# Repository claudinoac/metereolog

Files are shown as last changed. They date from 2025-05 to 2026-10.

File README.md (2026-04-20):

# 🌦️ Metereolog

This project involves the development of weather station and a platform capable of collecting data from various sensors, transmitting them to a central platform, storing them, and making them available through a web interface for visualization and analysis. The architecture is modular and scalable, using modern technologies for each stage of the process.

## 1. Project Overview

The main goal is to create a complete system for weather monitoring. This includes acquiring raw data from sensors, efficiently communicating this data to a central server, persistent storage in a time-series optimized database, and finally, visually and interactively presenting this data to users through a web application. Modularity allows for the easy addition of new sensors or replacement of components without affecting the whole system.

## 2. Project Architecture and Features

The architecture is distributed and based on microservices and asynchronous communication, as shown in the diagram. The main features include:

- **Distributed Data Collection:** Sensors are connected to embedded devices (HELTEC WiFi LoRa v3) that act as the network's "edge".
- **Local Gateways**: One local internet-connected dievice that aggregate data from stations in the region via LoRaWAN and transmit over the internet to the web platform via MQTT. 
- **Asynchronous, Message-Oriented Communication:** The MQTT protocol is used to transmit data from gateways to the message broker (RabbitMQ), ensuring low latency and resilience.
- **Centralized Message Processing:** RabbitMQ acts as a central hub for all sensor messages, enabling routing and processing by other components.
- **Optimized Data Persistence:** PostgreSQL and TimescaleDB provide a robust relational database optimized for time-series data.
- **RESTful API:** Facilitates communication between the frontend and backend, offering access to platform data and functionality.
- **Intuitive User Interface:** A modern, responsive web app allows for visualization and management of station data.
- **Containerization (Docker):** Simplifies deployment, portability, and environment management.
- **Modularity:** Each system component is independent, allowing isolated development and maintenance.

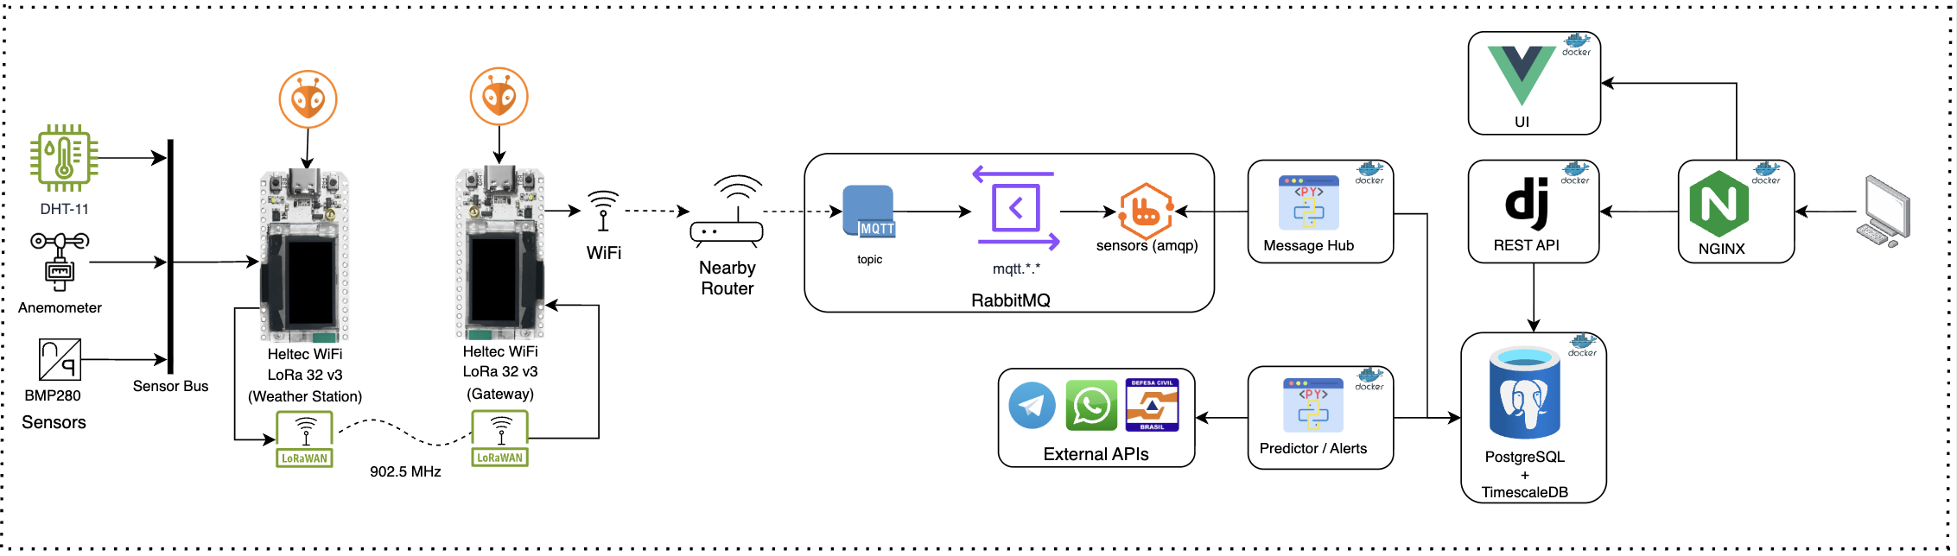
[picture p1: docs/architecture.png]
Project Architecture Diagram


## 3. Modular Project Structure and Technologies Used

### 3.1. Data Acquisition Module (Hardware and Firmware)

- **Sensors:**
  - **DHT-11:** Measures temperature and humidity.
  - **Anemometer:** Measures wind speed.
  - **Wind Direction Sensor:** Measures wind direction.
  - **MQ-6:** Measures petroleum-based gas such as propane and butane

- **Heltec WiFi LoRa 32 v3 (Sensor Bus / Weather Station):**
  - Microcontroller responsible for reading sensor data.
  - Acts as the local station’s “brain”.
  - Transmit sensor data to the Gateway node via LoRaWAN
  - **Technologies:** PlatformIO (C++ SDK), LoRaWAN, WiFi.
  - **Features:**
    - Base libraries for each sensor and peripherals (DHT-11, Anemometer, Wind Direction, WiFi, LoRa, etc.).
    - Structured firmware codebase.
    - Local wifi network to view real-time sensors data.
    - Firmware update via OTA (WiFi).
    - Doesn't depend on internet (data transmission via LoRaWAN).

- **Heltec WiFi LoRa 32 v3 (Gateway):**
  - Microcontroller responsible for receiving data from stations via LoRaWAN
  - Publishes sensor data from stations to the MQTT broker.
  - Firmware update via OTA (WiFi).
  - MQTT integration for data transmission.
  - **Technologies:**: PlatformIO (C++ SDK), LoRaWAN, WiFi.
  - **Features:**
    - Base libraries for peripherals (WiFi, LoRa, etc.)
    - Can route data from multiple stations on LoRaWAN reach.
    - Routes data to MQTT broker based on each station specs (credentials, topics).
    - Structured firmware codebase.
    - Firmware update via OTA (WiFi).

### 3.2. Communication and Messaging Module

- **RabbitMQ + MQTT Plugin:**
  - Central message broker for the system.
  - Receives MQTT messages from ESP-32.
  - Forwards them to subscribed components.
  - **Features:**
    - Reliable message delivery.
    - Decoupling producers and consumers.
    - Scalability.
  - **Topic Notation:**  
    - `<device_uid>/<sensor_uid>` = MQTT topics  
    - `mqtt.*` = wildcard listener  
    - `sensors (amqp)` = AMQP forwarding

### 3.3. Data Processing and Persistence Module

- **Message Hub:**
  - Consumes messages from RabbitMQ (`sensors (amqp)`).
  - Validates, transforms, enriches, and stores data.
  - **Technology:** Django (Python).
  - **Features:**
    - Sensor data processing logic.
    - Integration with PostgreSQL + TimescaleDB.

- **PostgreSQL + TimescaleDB:**
  - **PostgreSQL:** Stores users, devices, sensors, roles, permissions, dashboards.
  - **TimescaleDB:** Optimized for time-series sensor readings.
  - **Features:**
    - Efficient data storage (`SensorReading` table).
    - Complex historical query support.
    - System-wide entity management.

### 3.4. Backend Module (API)

- **Django REST API:**
  - Handles communication between frontend and backend.
  - Exposes data and operations through endpoints.
  - **Technology:** Django (Python).
  - **Features:**
    - CRUD endpoints for:
      - Organization (admin only)
      - Role
      - User
      - Device
      - Sensor
      - Dashboards
    - Login endpoint for user authentication.

### 3.5. Frontend Module (User Interface)

- **User Interface (UI):**
  - Web app for interacting with the system.
  - Visualizes sensor data using dashboards.
  - **Technologies:** Vue.js, Quasar, Chart.js.
  - **Features:**
    - Manage Organizations, Users, Devices, Sensors.
    - Create and view custom dashboards.
    - User login.

### 3.6. Web Server Module

- **NGINX:**
  - Reverse proxy for frontend and backend.
  - Serves frontend static files.
  - Manages routing, SSL/TLS, load balancing.
  - **Features:**
    - Optimized content delivery.
    - Unified socket for frontend/backend.
    - Simplified domain/port configuration.

## 4. General Project Features

- **Automated Data Collection:** Continuous readings of temperature, humidity, wind speed/direction, dust/smoke, air quality.
- **Reliable Data Transmission:** MQTT and RabbitMQ ensure delivery.
- **Efficient Time-Series Storage:** TimescaleDB optimized for volume and performance.
- **Entity Management:** Register and manage users, orgs, devices, sensors.
- **Real-Time & Historical Visualization:** Custom dashboards for monitoring.
- **Robust API:** Enables integration and future development.
- **Authentication & Authorization:** Role- and permission-based access.
- **Modularity & Scalability:** Easy to extend sensors, logic, or UI.
- **Simplified Deployment:** Docker streamlines setup and deployment.

## Database Schema
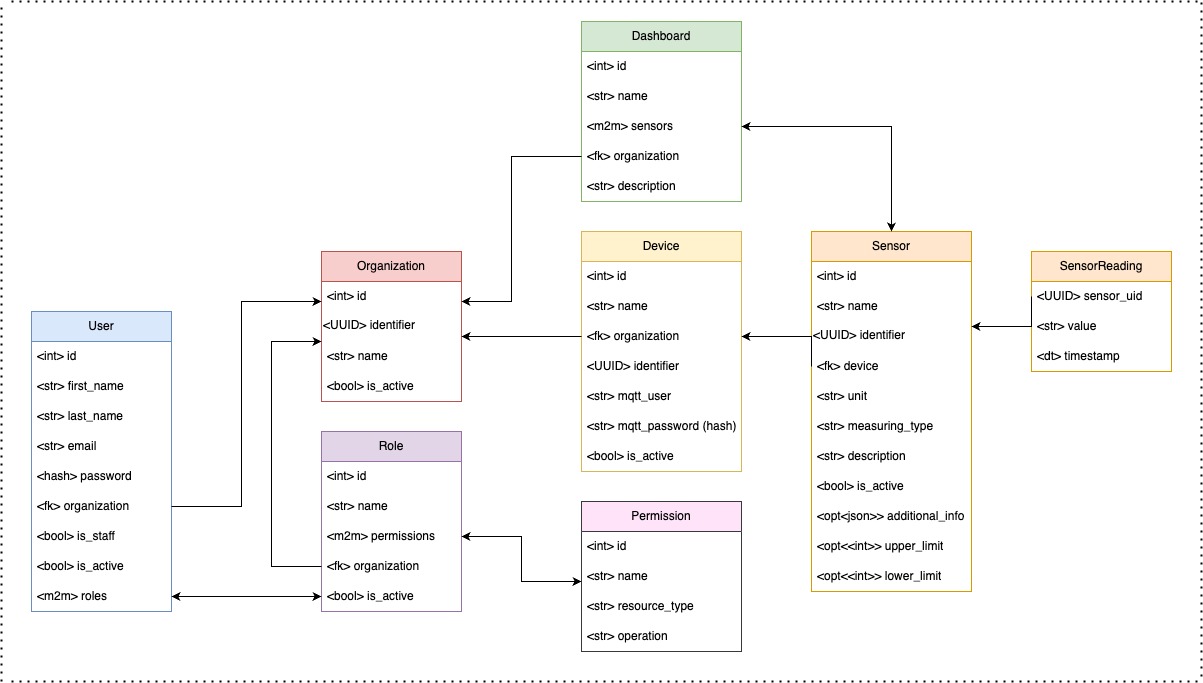
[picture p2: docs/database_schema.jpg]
Database Schema


The database schema represents the backend structure for a the web platform, where organizations can manage users, devices, sensors, and dashboards. It is designed with flexibility and scalability in mind, enabling role-based access control, sensor data collection, and customizable dashboards.

At the core of the system is the Organization entity, which acts as a tenant and groups together various resources such as users, devices, and dashboards. Each organization is uniquely identified by a UUID and can be either active or inactive.

Users are associated with a specific organization and can be marked as active or staff (indicating admin-level privileges). Users can have multiple roles, and roles determine their access levels. The Role entity is also organization-specific and connects to a list of Permissions, which define allowed operations on specific resource types, such as sensors or devices.

Devices are the physical units deployed in the field that collect environmental data. Each device belongs to an organization and has unique MQTT credentials for secure communication. Devices can contain multiple sensors, each with a unique identifier. A sensor records specific types of data (e.g., temperature, humidity, gas levels), stores its unit of measurement, and optionally includes configuration such as alert thresholds or additional metadata.

Sensor readings are stored in the SensorReading table, which logs values with timestamps. Each reading is linked to a sensor via its UUID, enabling time-series tracking and analysis of environmental metrics.

To support data visualization and accessibility, the platform includes a Dashboard entity. A dashboard groups together sensors from an organization and provides a human-readable layout to monitor and analyze data. Each dashboard can include multiple sensors and is associated with one organization.

In summary, the system is designed to:

* Support multiple independent organizations.

* Enable fine-grained user permissions through roles and permissions.

* Handle real-time data collection from sensors connected to devices.

* Provide dashboards for data visualization and management.

This schema makes it possible to build a robust, secure, and scalable platform.

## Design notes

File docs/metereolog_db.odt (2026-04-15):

DEC7129 – Banco de Dados I – Proposta de Projeto

Equipe: Alisson Claudino de Jesus (25150409)

Nome do Projeto: Metereolog – Plataforma de Monitoramento Metereológico

O projeto envolve o desenvolvimento de uma estação meteorológica e de uma plataforma capaz de coletar dados de diversos sensores, transmiti-los para uma plataforma central, armazená-los e disponibilizá-los por meio de uma interface web para visualização e análise.

Com arquitetura modular e escalável, utiliza-se de uma stack com Python/Django no back-end, Vue.JS e Quasar no front-end, RabbitMQ como broker MQTT e AMQP e PostgreSQL + TimescaleDB para banco de dados.

As estações metereológicas consistem de sensores conectados a módulos ESP-32, que se conectam via MQTT ao broker para envio dos dados. O back-end então coleta esses dados e armazena-os no banco de dados PostgreSQL, e com extensão TimescaleDB, otimizada para dados de series temporais.

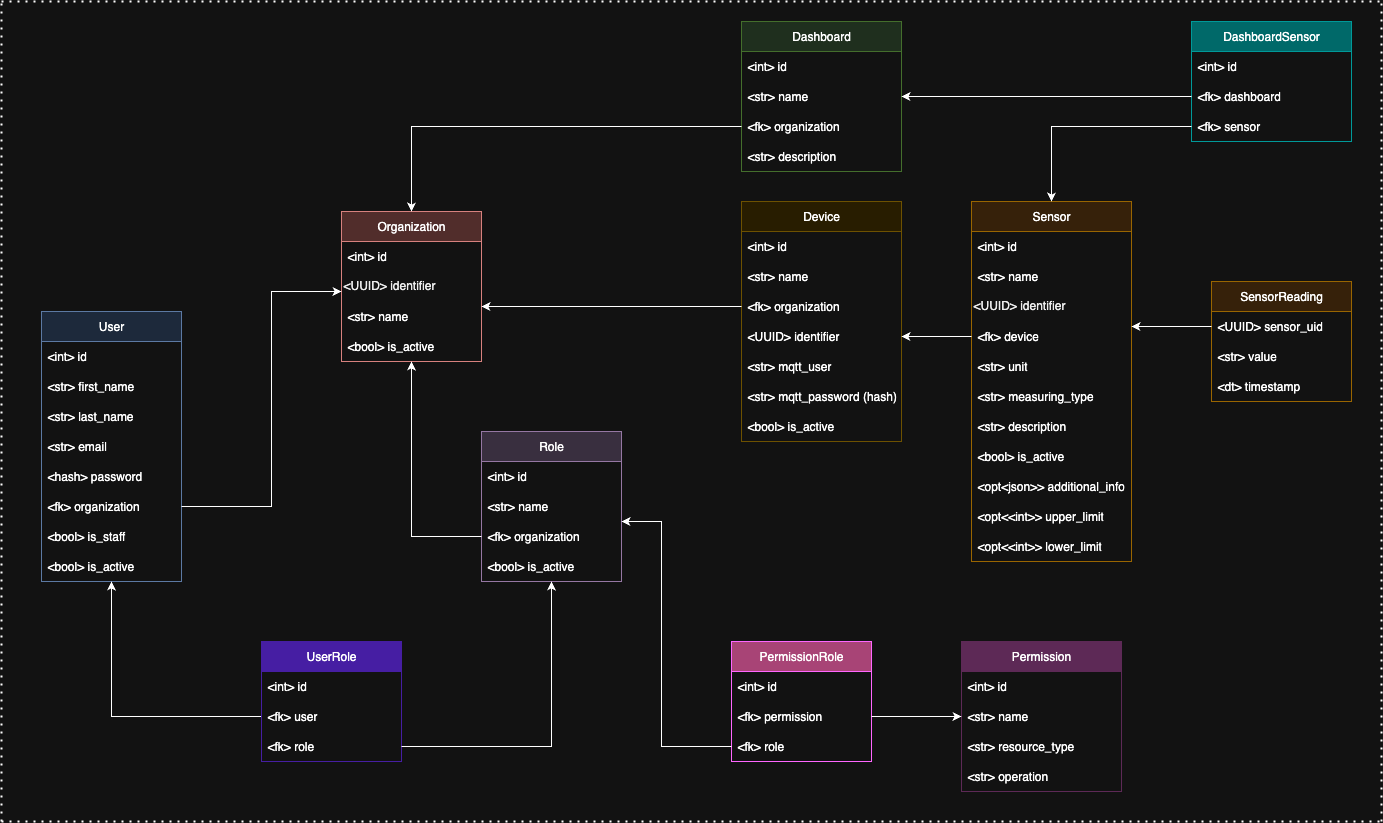
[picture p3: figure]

Rascunho de schema de banco de dados para referência

Diagrama Arquitetural da Plataforma

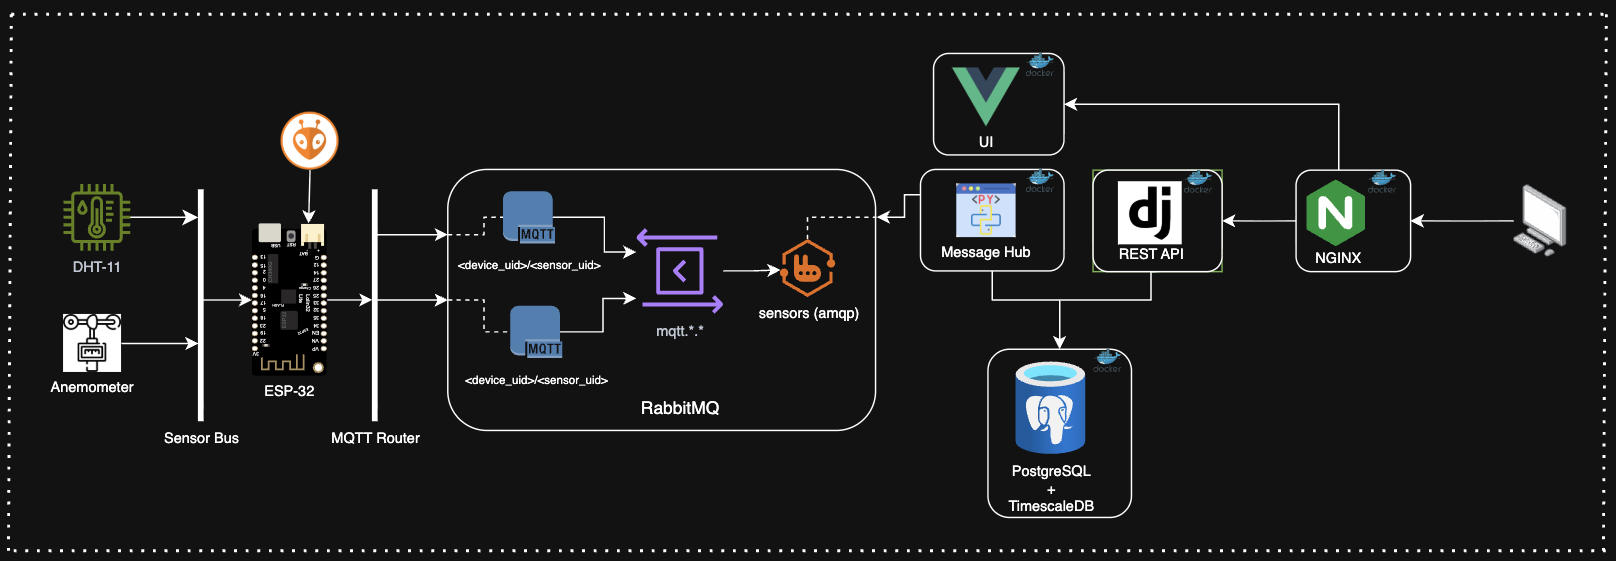
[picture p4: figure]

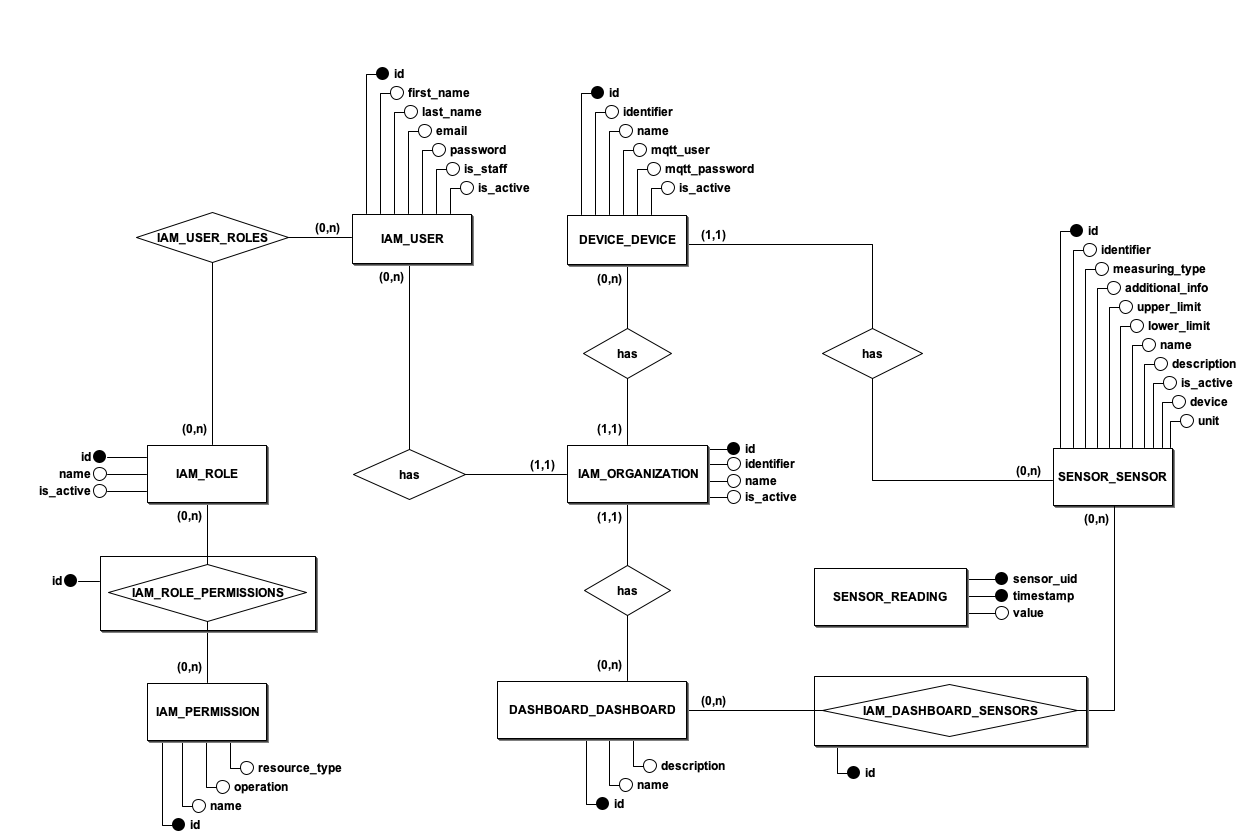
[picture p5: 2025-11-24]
docs/conceptual_diagram.png

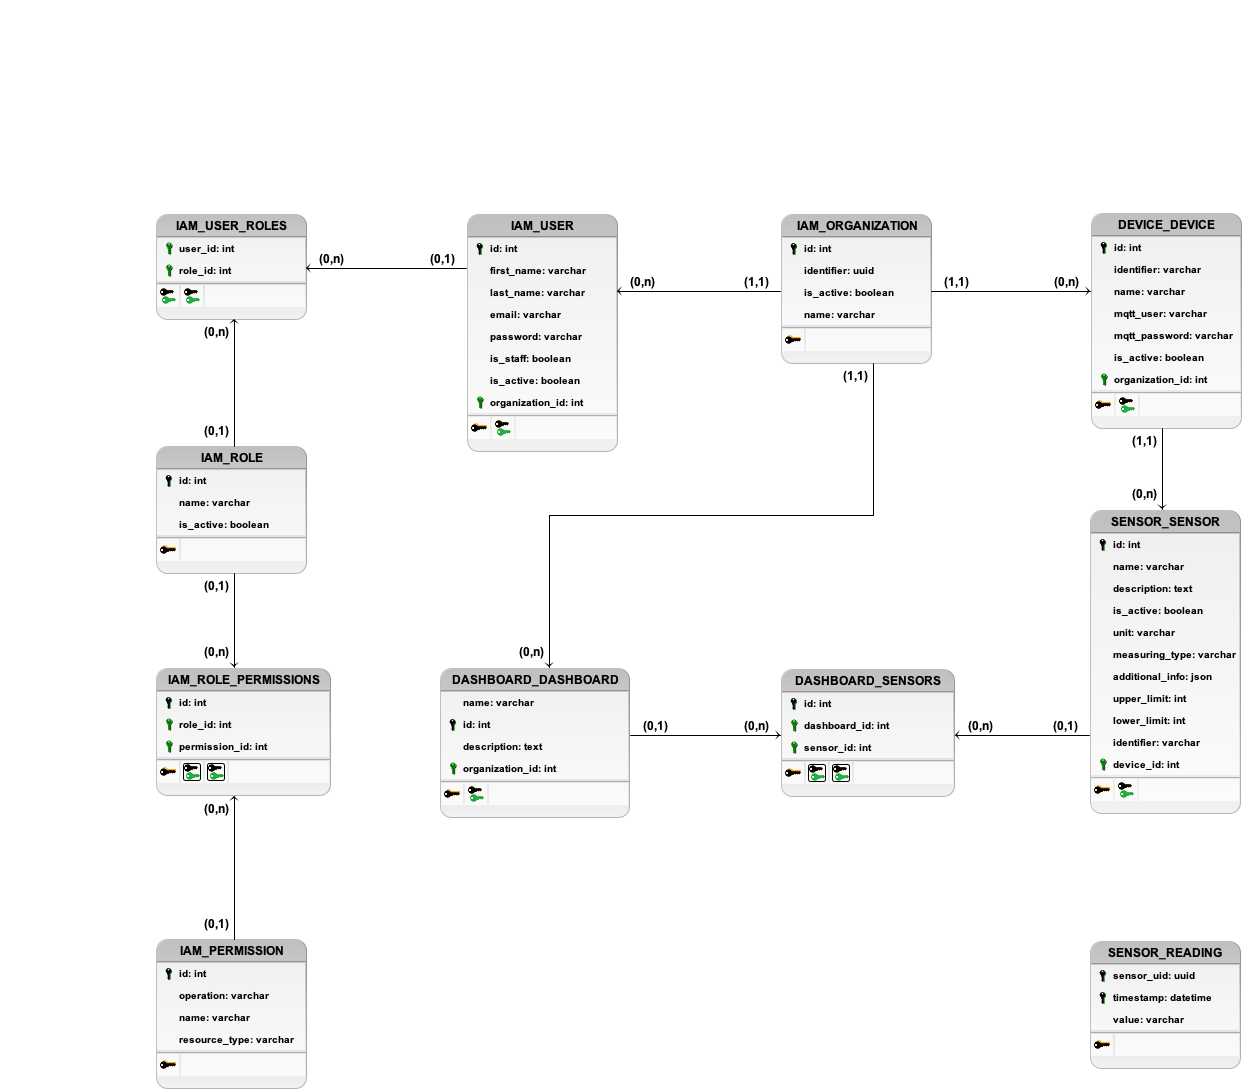
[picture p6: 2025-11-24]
docs/logical_diagram.png

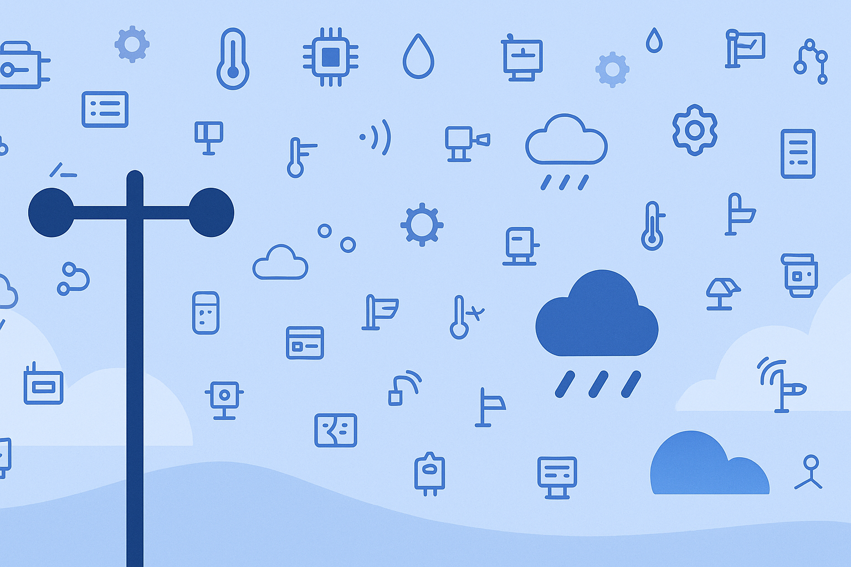
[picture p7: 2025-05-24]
frontend/src/assets/metereolog-cover.png

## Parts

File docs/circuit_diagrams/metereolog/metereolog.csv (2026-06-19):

Reference | Qty | Value | DNP | Exclude from BOM | Exclude from Board | Footprint | Datasheet
C1 | 1 | 1000uF
C2 | 1 | 100uF
HTC1 | 1 | 1 |  |  |  | heltec_wifi_lora:heltec_wifi_lora_v3
J1 | 1 | Anemoscope |  |  |  | TerminalBlock:TerminalBlock_MaiXu_MX126-5.0-02P_1x02_P5.00mm
J2 | 1 | DHT-11 |  |  |  | TerminalBlock:TerminalBlock_MaiXu_MX126-5.0-03P_1x03_P5.00mm
J3 | 1 | Anemometer |  |  |  | TerminalBlock:TerminalBlock_MaiXu_MX126-5.0-02P_1x02_P5.00mm
J4 | 1 | Voltmeter |  |  |  | Connector_PinSocket_2.54mm:PinSocket_1x03_P2.54mm_Vertical
J5 | 1 | Amperimeter |  |  |  | Connector_PinSocket_2.54mm:PinSocket_1x03_P2.54mm_Vertical
J6 | 1 | Jack-DC |  |  |  | Connector_BarrelJack:BarrelJack_Horizontal
J7 | 1 | volt_in |  |  |  | TerminalBlock:TerminalBlock_MaiXu_MX126-5.0-02P_1x02_P5.00mm
J8 | 1 | amp_in |  |  |  | TerminalBlock:TerminalBlock_MaiXu_MX126-5.0-02P_1x02_P5.00mm
J9 | 1 | BMP-280 |  |  |  | Connector_PinSocket_2.54mm:PinSocket_1x06_P2.54mm_Vertical
J10 | 1 | Pluviometer |  |  |  | TerminalBlock:TerminalBlock_MaiXu_MX126-5.0-02P_1x02_P5.00mm
lm1 | 1 |  |  |  |  | Converter_DCDC:lm2596_board
R1 | 1 | 16k |  |  |  | Resistor_THT:R_Axial_DIN0207_L6.3mm_D2.5mm_P7.62mm_Horizontal
R2,R3 | 2 | 10k |  |  |  | Resistor_THT:R_Axial_DIN0207_L6.3mm_D2.5mm_P7.62mm_Horizontal
rtcsd1 | 1 |  |  |  |  | logical_converter:rtc_sdcard
vc1,vc2 | 2 |  |  |  |  | logical_converter:logical_converter

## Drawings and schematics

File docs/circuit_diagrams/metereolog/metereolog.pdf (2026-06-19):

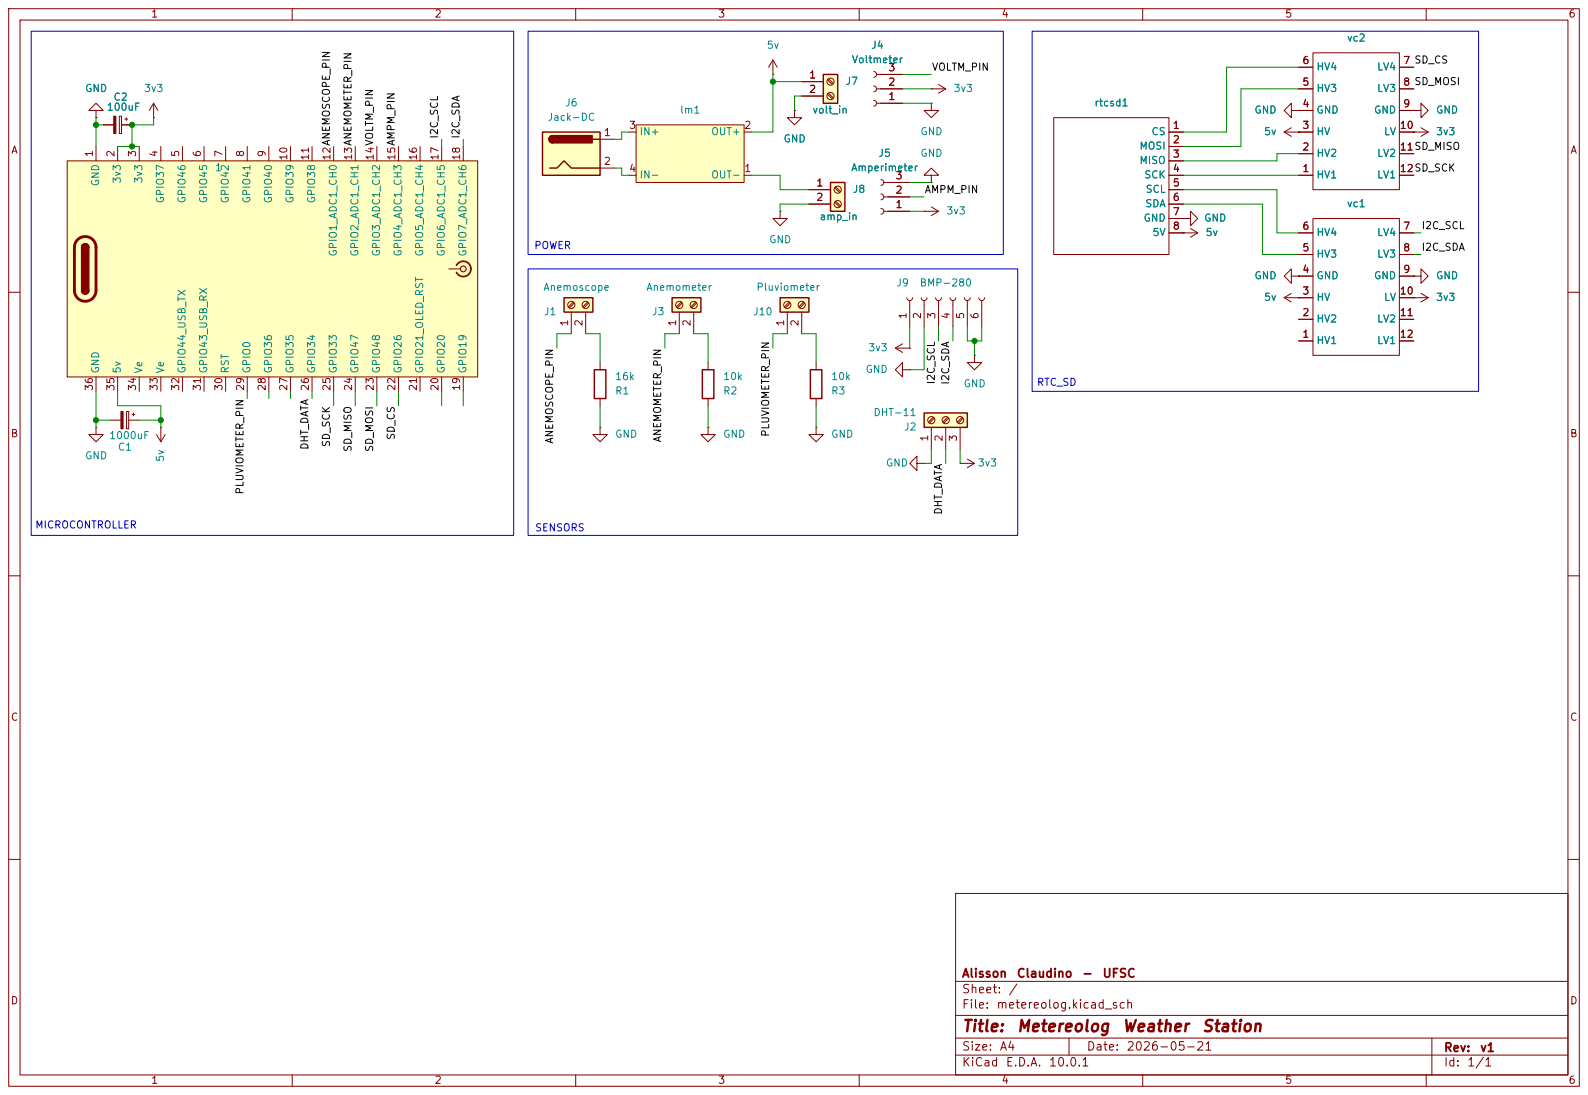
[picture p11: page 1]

9 GPIO39 10 GPIO38 11 GPIO1_ADC1_CH0 12 GPIO2_ADC1_CH1 13 GPIO3_ADC1_CH2 14 GPIO4_ADC1_CH3 15 GPIO5_ADC1_CH4 16 GPIO6_ADC1_CH5 17 GPIO7_ADC1_CH6 18 GPIO19 19 GPIO20 20 GPIO21_OLED_RST 21 GPIO26 22 GPIO48 23 GPIO47 24 GPIO33 25 GPIO34 26 GPIO35 27 GPIO36 28 GPIO0 29 RST 30 GPIO43_USB_RX 31 GPIO44_USB_TX 32 Ve 33 Ve 34 5v 35 GND 36
vc1 GND GND

Alisson Claudino - UFSC
Sheet: /
File: metereolog.kicad_sch
Title: Metereolog Weather Station

Size: A4 | Rev: v1
KiCad E.D.A. 10.0.1 | Id: 1/1

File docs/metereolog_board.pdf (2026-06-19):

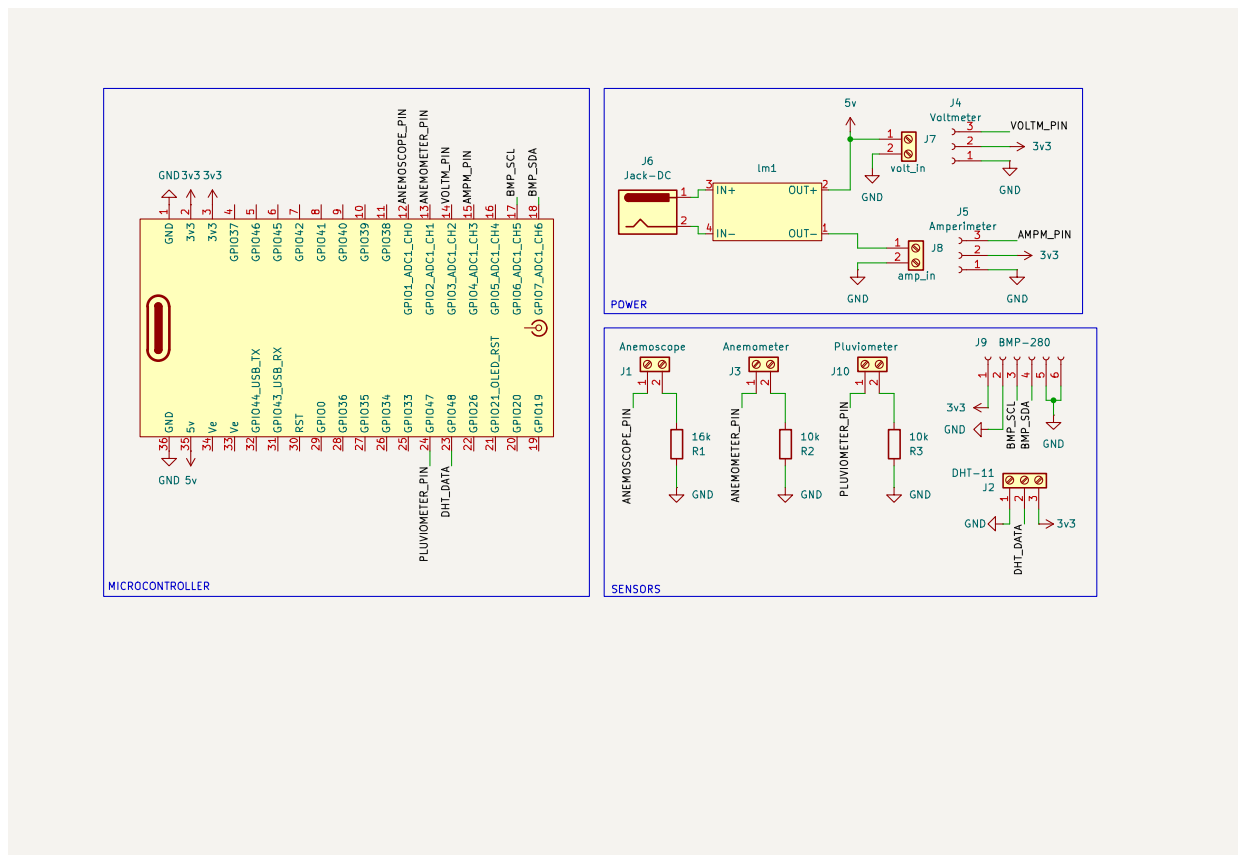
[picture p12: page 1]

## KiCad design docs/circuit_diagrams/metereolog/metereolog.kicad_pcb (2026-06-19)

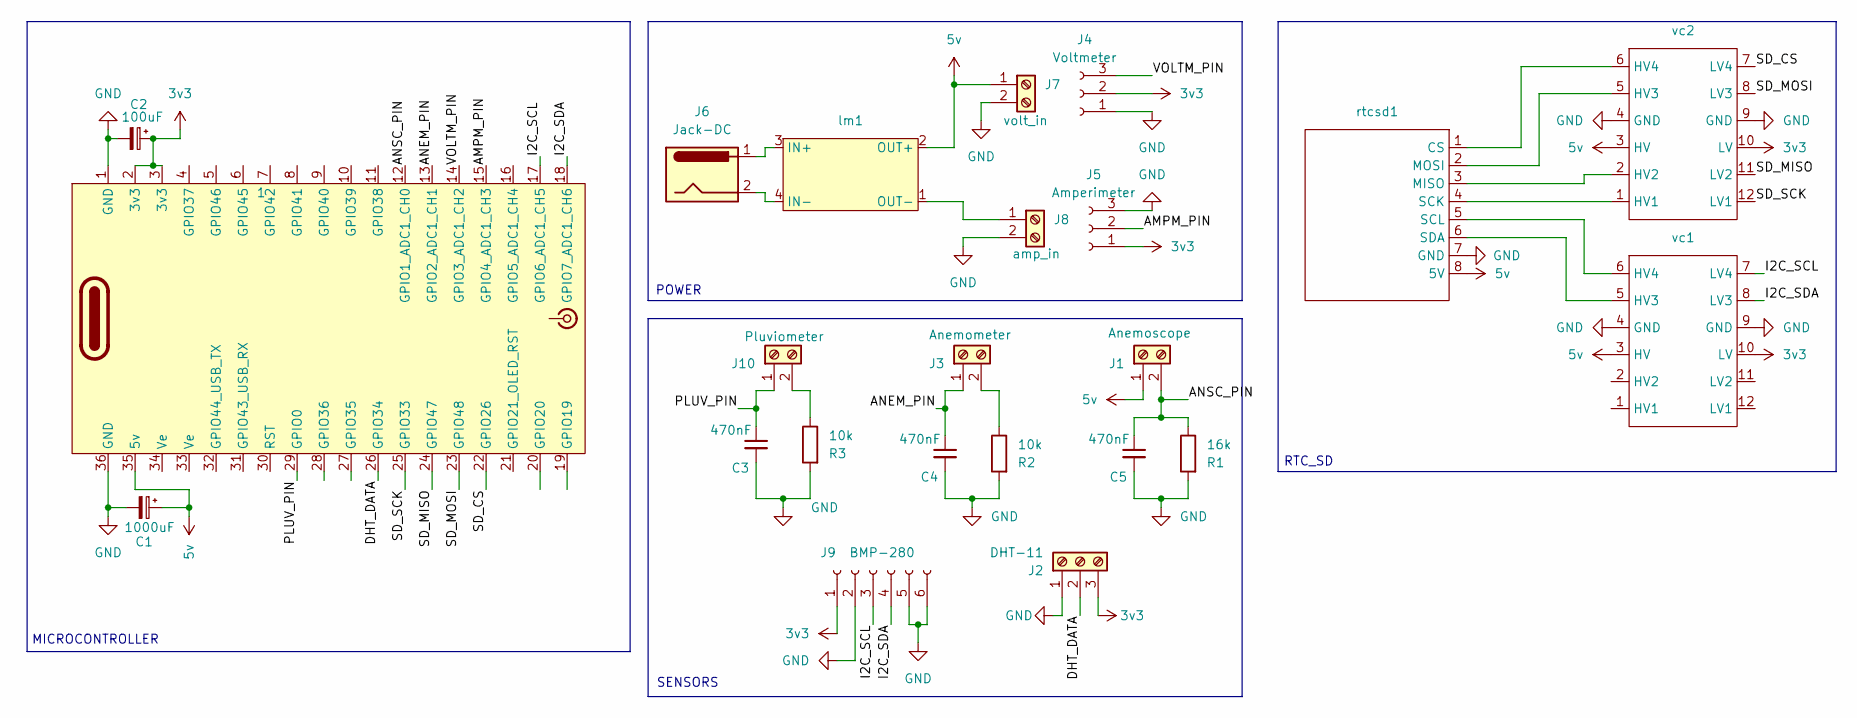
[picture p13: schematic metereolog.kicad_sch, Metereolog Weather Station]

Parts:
C1: 1000uF; C_Radial_D10.0mm_H16.0mm_P5.00mm
C2: 100uF; C_Radial_D6.3mm_H11.0mm_P2.50mm
C3, C4, C5: 470nF; C_Rect_L7.0mm_W3.5mm_P5.00mm
HTC1: 1; heltec_wifi_lora_v3
J1: Anemoscope; TerminalBlock_MaiXu_MX126-5.0-02P_1x02_P5.00mm
J2: DHT-11; TerminalBlock_MaiXu_MX126-5.0-03P_1x03_P5.00mm
J3: Anemometer; TerminalBlock_MaiXu_MX126-5.0-02P_1x02_P5.00mm
J4: Voltmeter; PinSocket_1x03_P2.54mm_Vertical
J5: Amperimeter; PinSocket_1x03_P2.54mm_Vertical
J6: Jack-DC; BarrelJack_Horizontal
J7: volt_in; TerminalBlock_MaiXu_MX126-5.0-02P_1x02_P5.00mm
J8: amp_in; TerminalBlock_MaiXu_MX126-5.0-02P_1x02_P5.00mm
J9: BMP-280; PinSocket_1x06_P2.54mm_Vertical
J10: Pluviometer; TerminalBlock_MaiXu_MX126-5.0-02P_1x02_P5.00mm
R1: 16k; R_Axial_DIN0207_L6.3mm_D2.5mm_P7.62mm_Horizontal
R2, R3: 10k; R_Axial_DIN0207_L6.3mm_D2.5mm_P7.62mm_Horizontal
lm1: lm2596_board
rtcsd1: rtc_sdcard
vc1, vc2: logical_converter

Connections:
3v3: C2.1, HTC1.2 (3v3), HTC1.3 (3v3), J2.3, J4.2, J5.1, J9.1, vc1.10 (LV), vc2.10 (LV)
5v: C1.1, HTC1.35 (5v), J1.1, J7.1, lm1.2 (OUT+), rtcsd1.8 (5V), vc1.3 (HV), vc2.3 (HV)
/AMPM_PIN: HTC1.15 (GPIO4_ADC1_CH3), J5.2
/ANEM_PIN: C4.1, HTC1.13 (GPIO2_ADC1_CH1), J3.1
/ANSC_PIN: C5.1, HTC1.12 (GPIO1_ADC1_CH0), J1.2, R1.1
/DHT_DATA: HTC1.26 (GPIO34), J2.2
/I2C_SCL: HTC1.17 (GPIO6_ADC1_CH5), J9.3, vc1.7 (LV4)
/I2C_SDA: HTC1.18 (GPIO7_ADC1_CH6), J9.4, vc1.8 (LV3)
/PLUV_PIN: C3.1, HTC1.29 (GPIO0), J10.1
/SD_CS: HTC1.22 (GPIO26), vc2.7 (LV4)
/SD_MISO: HTC1.24 (GPIO47), vc2.11 (LV2)
/SD_MOSI: HTC1.23 (GPIO48), vc2.8 (LV3)
/SD_SCK: HTC1.25 (GPIO33), vc2.12 (LV1)
/VOLTM_PIN: HTC1.14 (GPIO3_ADC1_CH2), J4.3
GND: C1.2, C2.2, C3.2, C4.2, C5.2, HTC1.1 (GND), HTC1.36 (GND), J2.1, J4.1, J5.3, J7.2, J8.2, J9.2, J9.5, J9.6, R1.2, R2.2, R3.2, rtcsd1.7 (GND), vc1.4 (GND), vc1.9 (GND), vc2.4 (GND), vc2.9 (GND)
unnamed: J3.2, R2.1
unnamed: J8.1, lm1.1 (OUT-)
unnamed: J10.2, R3.1
unnamed: J6.1, lm1.3 (IN+)
unnamed: J6.2, lm1.4 (IN-)
unnamed: rtcsd1.1 (CS), vc2.6 (HV4)
unnamed: rtcsd1.3 (MISO), vc2.2 (HV2)
unnamed: rtcsd1.2 (MOSI), vc2.5 (HV3)
unnamed: rtcsd1.4 (SCK), vc2.1 (HV1)
unnamed: rtcsd1.5 (SCL), vc1.6 (HV4)
unnamed: rtcsd1.6 (SDA), vc1.5 (HV3)

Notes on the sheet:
MICROCONTROLLER
SENSORS
POWER
RTC_SD

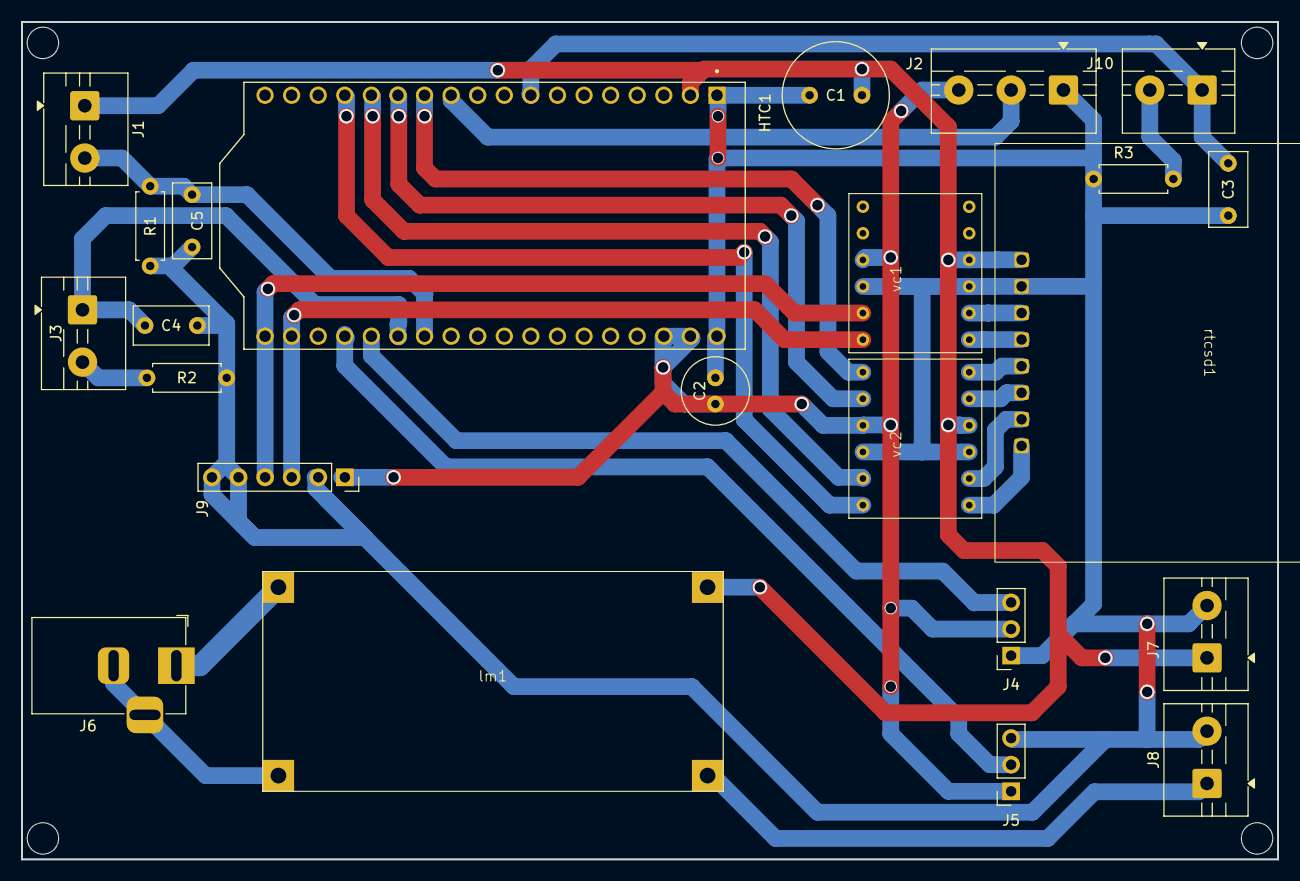
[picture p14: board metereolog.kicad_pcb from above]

Board: 2 copper layers, 120.0 x 80.0 mm, 23 parts (0 on the bottom side), 26 nets.

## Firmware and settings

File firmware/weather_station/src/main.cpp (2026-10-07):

#include <stdio.h>
#include <freertos/FreeRTOS.h>
#include <freertos/task.h>
#include <driver/gpio.h>
#include <esp_log.h>
#include <sdkconfig.h>
#include <driver/gpio.h>
#include <Arduino.h>
#include <ArduinoJson.h>
#include <ESPAsyncWebServer.h>
#include <ElegantOTA.h>
#include <spi.h>
#include <SD.h>
#include <esp_system.h>

#include "main.html.hpp"
#include "dht_sensor.hpp"
#include "wifi.hpp"
#include "anemoscope.hpp"
#include "anemometer.hpp"
#include "pluviometer.hpp"
#include "bmp.hpp"
#include "voltmeter.hpp"
#include "amperimeter.hpp"
#include "lora.hpp"
#include "oled.hpp"
#include "rtc.hpp"
#include "ina219.hpp"
#include "ads1115.hpp"

#define ELEGANTOTA_USE_ASYNC_WEBSERVER 1
#define uS_TO_S_FACTOR 1000000ULL
#define TIME_TO_SLEEP  5
#define TX_CYCLES 5
#define PRG_PIN 0

/* ============ WIFI CONFIGS ===================*/ 
const char* ap_ssid = ENV_WIFI_AP_SSID;
const char* ap_pwd = ENV_WIFI_AP_PWD;
const char* ssid = ENV_WIFI_SSID;
const char* password = ENV_WIFI_PASS;

Wifi *wifi_client;

/* ============ OTA CONFIGS ===================*/ 
const char *ota_username = ENV_OTA_USER;
const char *ota_password = ENV_OTA_PASS;

/* ============ CLOCK CONFIGS ===================*/ 
unsigned long epochTime; 

/* ================= LORA CONFIGS ===============*/
#define NSS_LORA   (gpio_num_t)   8
#define DIO1_LORA  (gpio_num_t)   14
#define RESET_LORA (gpio_num_t)   12
#define BUSY_LORA  (gpio_num_t)   13
// #define BAND          915.6
#define BAND          917
#define BANDWIDTH     62.5
#define SPREADING_FACTOR 10
#define CODING_RATE   4/5
#define LORA_POWER    22.0
const char *device_id = ENV_DEVICE_ID;


LoRa *lora;

/* ================= OLED CONFIGS ===============*/

#define OLED_SDA  (gpio_num_t)  17
#define OLED_SCL  (gpio_num_t)  18
#define OLED_RST  (gpio_num_t)  21
#define VEXT_PIN  (gpio_num_t)  36
#define WIDTH  128
#define HEIGHT 64

OLED *display;

/*  ==============  I2C Config ================o */

#define I2C_SDA (gpio_num_t) 7
#define I2C_SCL (gpio_num_t) 6

TwoWire *i2c_channel = new TwoWire(1);

/* ============ SDCARD CONFIGS ===================*/ 

#define SD_SCLK 48 // SCK
#define SD_MISO 26 // MISO
#define SD_MOSI 47 // MOSI
#define SD_CS 33 // CS

SPIClass *sd_spi = nullptr; 

/* ============ SENSOR CONFIGS ===================*/ 
#define ANEMOSCOPE_PIN (gpio_num_t) 2
#define ANEMOMETER_PIN (gpio_num_t) 5
#define DHT_PIN (gpio_num_t) 34
#define PLUVIOMETER_PIN (gpio_num_t) 35
#define SEA_LEVEL_HPA (1013.25)
#define VOLTMETER_PIN (gpio_num_t) 3
#define AMPERIMETER_PIN (gpio_num_t) 4
#define VOLTMETER_UP_RES 200000
#define VOLTMETER_LOW_RES 51000
#define AMPERIMETER_UP_RES 1000
#define AMPERIMETER_LOW_RES 2000

const char *dht_temp_id = ENV_DHT_TEMP_ID;
const char *dht_hum_id = ENV_DHT_HUM_ID;
const char *anemometer_id = ENV_ANEMOMETER_ID;
const char *anemoscope_id = ENV_ANEMOSCOPE_ID;
const char *pluviometer_id = ENV_PLUVIOMETER_ID;
const char *bmp_temp_id = ENV_BMP_TEMP_ID;
const char *bmp_alt_id = ENV_BMP_ALT_ID;
const char *bmp_press_id = ENV_BMP_PRESS_ID;
const char *voltmeter_id = ENV_VOLTMETER_ID;
const char *amperimeter_id = ENV_AMPERIMETER_ID;


DHTSensor *dht_sensor;
DHTInfo dht_reading;

Anemometer *anemometer;
AnemometerInfo anemometer_reading;

Anemoscope *anemoscope;
WindDirectionInfo wind_direction_reading;

Pluviometer *pluviometer;
PluviometerInfo pluviometer_reading;

BMPSensor *bmp_sensor;
BMPInfo bmp_reading;

Voltmeter *voltmeter;
VoltmeterInfo voltmeter_reading;

Amperimeter *amperimeter;
AmperimeterInfo amperimeter_reading;

RTC *rtc;

INA219 *power_sensor;
PowerInfo power_info;

ADS1115 *adc_sensor;

/* ============ MISC VARIABLES ===================*/ 

typedef struct __attribute__((packed)) {
    char device_id[33];
    unsigned long timestamp;
    char wind_dir[3];
    float dht_hum;
    float dht_temp;
    float wind_speed;
    float rain_gauge;
    float bmp_temp;
    float bmp_alt;
    float bmp_press;
    float voltage;
    float current;
    float power;
} Packet;

JsonDocument doc;

AsyncWebServer server(80);

char msg_buffer[255]; 

volatile bool data_loop_running = false;
volatile bool is_display_enabled = false;
Packet *current_packet;
hw_timer_t *timer = NULL;
SemaphoreHandle_t global_lock;

/* ============ GLOBAL UTIL METHODS ===================*/ 

String serialize_packet(const Packet *p) {
    String raw_packet = "";
    raw_packet += String(p->device_id) + "|";
    raw_packet += String(p->timestamp) + "|";
    raw_packet += String(p->wind_dir) + "|";
    raw_packet += String(p->dht_hum) + "|";
    raw_packet += String(p->dht_temp) + "|";
    raw_packet += String(p->wind_speed) + "|";
    raw_packet += String(p->rain_gauge) + "|";
    raw_packet += String(p->bmp_temp) + "|";
    raw_packet += String(p->bmp_alt) + "|";
    raw_packet += String(p->bmp_press) + "|";
    raw_packet += String(p->voltage) + "|";
    raw_packet += String(p->current) + "|";
    raw_packet += String(p->power);
    return raw_packet;
}

void pretty_print_packet(const Packet* p) {
  Serial.println("Packet {");
  Serial.print("    device_id = ");   Serial.print(p->device_id);  Serial.println(",");
  Serial.print("    timestamp = ");   Serial.print(p->timestamp);  Serial.println(",");
  Serial.print("    wind_dir = ");    Serial.print(p->wind_dir);   Serial.println(",");
  Serial.print("    dht_hum = ");     Serial.print(p->dht_hum);    Serial.println(",");
  Serial.print("    dht_temp = ");    Serial.print(p->dht_temp);   Serial.println(",");
  Serial.print("    wind_speed = ");  Serial.print(p->wind_speed); Serial.println(",");
  Serial.print("    rain_gauge = ");  Serial.print(p->rain_gauge); Serial.println(",");
  Serial.print("    bmp_temp = ");    Serial.print(p->bmp_temp);   Serial.println(",");
  Serial.print("    bmp_alt = ");     Serial.print(p->bmp_alt);    Serial.println(",");
  Serial.print("    bmp_press = ");   Serial.print(p->bmp_press);  Serial.println(",");
  Serial.print("    voltage = ");     Serial.print(p->voltage);    Serial.println(",");
  Serial.print("    current = ");     Serial.print(p->current);    Serial.println(",");
  Serial.print("    power = ");       Serial.print(p->power);
  Serial.println("}");
}



void onOTAStart() {
    display->display_message("Updating firmware...");
}

void onOTAEnd(bool success) {
    display->display_message("Update finished. \nRebooting...");
}

void onOTAProgress(size_t current, size_t final) {
    // display->display_message("Updating firmware...\nProgress: " + String(float(current) / float(final)));
}

void setup_i2c() {
    // pinMode(I2C_SCL, OUTPUT);
    // for (int i = 0; i < 8; i++) {
    //     digitalWrite(I2C_SCL, HIGH);
    //     delayMicroseconds(3);
    //     digitalWrite(I2C_SCL, LOW);
    //     delayMicroseconds(3);
    // }
    // pinMode(I2C_SCL, INPUT_PULLUP);
    // pinMode(I2C_SDA, INPUT_PULLUP);
    if (!i2c_channel->begin(I2C_SDA, I2C_SCL)) {
        Serial.println("Cannot initialize custom bmp I2C Channel");
    };
    i2c_channel->setTimeout(100);
}

void setup_sensors() {
    dht_sensor = new DHTSensor(DHT_PIN, DHT_MODEL_DHT22);
    anemoscope = new Anemoscope(ANEMOSCOPE_PIN);
    anemometer = new Anemometer(ANEMOMETER_PIN);
    pluviometer = new Pluviometer(PLUVIOMETER_PIN);
    bmp_sensor = new BMPSensor(i2c_channel, SEA_LEVEL_HPA);
    // voltmeter = new Voltmeter(VOLTMETER_PIN, VOLTMETER_UP_RES, VOLTMETER_LOW_RES);
    // amperimeter = new Amperimeter(AMPERIMETER_PIN, AMPERIMETER_UP_RES, AMPERIMETER_LOW_RES);
    power_sensor = new INA219(i2c_channel);
    adc_sensor = new ADS1115(i2c_channel);
}

void setup_rtc() {
    rtc = new RTC(i2c_channel);
}

// void diagnoseSdFailure() {
//     Serial.println("\n--- SD Diagnostics ---");
// 
//     // 1. Check if SPI bus responds at all (pull CS low, send dummy byte, check MISO)
//     sd_spi->begin(SD_SCLK, SD_MISO, SD_MOSI, SD_CS);
//     pinMode(SD_CS, OUTPUT);
//     digitalWrite(SD_CS, HIGH);
//     delay(100);
// 
//     // Send 10 dummy bytes with CS high (required SD init sequence)
//     for (int i = 0; i < 10; i++) {
//         sd_spi->transfer(0xFF);
//     }
// 
//     digitalWrite(SD_CS, LOW);
//     delay(10);
//     uint8_t response = sd_spi->transfer(0xFF);
//     digitalWrite(SD_CS, HIGH);
// 
//     Serial.printf("SPI dummy byte response: 0x%02X (0xFF = line idle/ok, 0x00 = MISO stuck low)\n", response);
// 
//     // 2. Try SD init at very low speed (400 kHz is SD spec for init)
//     Serial.println("\nTrying SD.begin() at 400kHz...");
//     if (SD.begin(SD_CS, *sd_spi, 400000)) {
//         Serial.println("SUCCESS at 400kHz — your clock speed was too high");
//         return;
//     }
// 
//     // 3. Try with FSPI instead
//     Serial.println("Failed. Trying FSPI bus...");
//     SPIClass spi2 = SPIClass(FSPI);
//     spi2.begin(SD_SCLK, SD_MISO, SD_MOSI, SD_CS);
//     if (SD.begin(SD_CS, spi2, 400000)) {
//         Serial.println("SUCCESS with FSPI — use SPIClass(FSPI) in your code");
//         return;
//     }
// 
//     // 4. Check card type after a failed begin
//     Serial.println("Failed both buses. Checking card type...");
//     uint8_t cardType = SD.cardType();
//     if (cardType == CARD_NONE) {
//         Serial.println("Card type: NONE — card not detected at all");
//         Serial.println("  -> Check wiring, CS pin, and 3.3V power");
//     } else if (cardType == CARD_UNKNOWN) {
//         Serial.println("Card type: UNKNOWN — card detected but not recognized");
//         Serial.println("  -> Try reformatting card as FAT32");
//     } else {
//         Serial.printf("Card type: %d — card found but mount still failed\n", cardType);
//         Serial.println("  -> Filesystem may be corrupted, try reformatting");
//     }
// 
//     // 5. MISO pin state check
//     pinMode(SD_MISO, INPUT);
//     int misoState = digitalRead(SD_MISO);
//     Serial.printf("\nMISO pin state (idle): %s\n", misoState ? "HIGH (ok)" : "LOW (stuck — bad wiring or short)");
// 
//     // 6. CS pin state check  
//     pinMode(SD_CS, INPUT_PULLUP);
//     delay(10);
//     int csState = digitalRead(SD_CS);
//     Serial.printf("CS pin state: %s\n", csState ? "HIGH (ok)" : "LOW (stuck — check for short)");
// }

void setup_sdcard() {
    sd_spi = new SPIClass(HSPI);
    sd_spi->begin(SD_SCLK, SD_MISO, SD_MOSI, SD_CS);
    pinMode(SD_CS, OUTPUT);
    digitalWrite(SD_CS, HIGH);
    int countdown = 3;
    while (!SD.begin(SD_CS, *sd_spi, 4000000)) {
        Serial.println("Card Mount Failed. Retrying...");
        delay(500);
        countdown -= 1;
        if (countdown < 1) {
            // diagnoseSdFailure();
            throw std::runtime_error("SDCARD not configured.");
        }
    }
    Serial.println("Card Mounted");
    File root = SD.open("/");
    if (root) {
        root.close();
        Serial.println("SD ready.");
    }
}

bool write_line(String filename, String line) {
    File file = SD.open("/" + filename, FILE_APPEND);
    if (file) {
        Serial.println("Writing to file: " + filename);
        file.println(line);
        file.close();
        Serial.println("Written to file!");
        return true;
    }
    Serial.println("Cannot open file: " + filename);
    return false;
}

void setup_network() {
    lora = new LoRa(NSS_LORA, DIO1_LORA, RESET_LORA, BUSY_LORA, BAND, BANDWIDTH, SPREADING_FACTOR, CODING_RATE, LORA_POWER, Receptor);
    wifi_client = new Wifi((char *)ssid, (char *)password, (char *)ap_ssid, (char *)ap_pwd);
    lora->begin();
}

void setup_display() {
    display = new OLED(OLED_SDA, OLED_SCL, OLED_RST, VEXT_PIN, WIDTH, HEIGHT);
    display->begin();
}

void setup_webserver() {
  server.on("/stats", HTTP_GET, [](AsyncWebServerRequest *request) {
    JsonDocument stats_doc;
    stats_doc["timestamp"] = doc[dht_temp_id]["timestamp"];

    stats_doc["anemometer"] = doc[anemometer_id]["value"] ? doc[anemometer_id]["value"] : 0;
    stats_doc["wind_dir"] = doc[anemoscope_id]["value"];
    stats_doc["voltmeter"] = doc[voltmeter_id]["value"];
    stats_doc["amperimeter"] = doc[amperimeter_id]["value"];

    JsonObject bmp = stats_doc["bmp"].to<JsonObject>();
    bmp["temperature"] = doc[bmp_temp_id]["value"];
    bmp["pressure"] = doc[bmp_press_id]["value"];
    bmp["altitude"] = doc[bmp_alt_id]["value"];

    JsonObject dht_11 = stats_doc["dht_11"].to<JsonObject>();
    dht_11["temperature"] = doc[dht_temp_id]["value"];
    dht_11["humidity"] = doc[dht_hum_id]["value"];
    
    String stats_output;
    serializeJson(stats_doc, stats_output);
    request->send(200, "application/json", stats_output);
  });

  server.on("/", HTTP_GET, [](AsyncWebServerRequest *request) {
    request->send(200, "text/html", index_html);
  });
 
  ElegantOTA.begin(&server);
  ElegantOTA.setAuth(ota_username, ota_password);
  ElegantOTA.onStart(onOTAStart);
  ElegantOTA.onProgress(onOTAProgress);
  ElegantOTA.onEnd(onOTAEnd);
  server.begin();
  Serial.println("HTTP server started");
}

void loop_webserver() {
  ElegantOTA.loop();
}

void read_sensors() {
    current_packet = (Packet *)malloc(sizeof(Packet));
    time_t current_time = rtc->get_time();
    current_packet->timestamp = current_time;
    strcpy(current_packet->device_id, device_id);
    dht_reading = dht_sensor->read();
    current_packet->dht_temp = dht_reading.temperature;
    current_packet->dht_hum = dht_reading.humidity; 
    wind_direction_reading = anemoscope->read();
    strcpy(current_packet->wind_dir, wind_direction_reading.direction);
    anemometer_reading = anemometer->read();
    current_packet->wind_speed = anemometer_reading.wind_speed;
    pluviometer_reading = pluviometer->read();
    current_packet->rain_gauge = pluviometer_reading.collected_rain_mm;
    bmp_reading = bmp_sensor->read();
    current_packet->bmp_temp = bmp_reading.temperature;
    current_packet->bmp_alt = bmp_reading.altitude;
    current_packet->bmp_press = bmp_reading.pressure;
    power_info = power_sensor->read();
    current_packet->voltage = power_info.voltage;
    current_packet->current = power_info.current;
    current_packet->power = power_info.power;
}

void IRAM_ATTR turn_off_display() {
    is_display_enabled = false;
}

void IRAM_ATTR run_display() {
    is_display_enabled = true;
}

void data_loop(void *pvParameters) {
    while(true) {
        int lora_error_count = 0;
        String raw_packet = "";
        if (xSemaphoreTake(global_lock, portMAX_DELAY) == pdTRUE) {
            read_sensors();
            raw_packet = serialize_packet(current_packet);
            pretty_print_packet(current_packet);
            xSemaphoreGive(global_lock);
        }
        if (!raw_packet.isEmpty()) {
            // write_line("aru_0_data.txt", raw_packet);
            if (lora->send_message(raw_packet)) {
                lora_error_count = 0;
            } else {
                if (lora_error_count >= 3) {
                    esp_restart();
                } else {
                    lora_error_count += 1;
                }
            };
            delay(2000);
        }
    }
}
void setup(){
    global_lock = xSemaphoreCreateMutex();
    Serial.begin(115200);
    Serial.println("Metereolog Weather Station ARU 01 Starting...");
    setup_display();
    display->display_message("Metereolog Weather Station\nARU 01 Starting...");
    try {
        setup_i2c();
        setup_network();
        setup_rtc();
        setup_sensors();
    } catch (const std::runtime_error& error) {
        esp_restart();
    }
    // setup_sdcard();
    pinMode(PRG_PIN, INPUT_PULLUP);
    attachInterrupt(digitalPinToInterrupt(PRG_PIN), run_display, FALLING);
    // setup_webserver();
    display->display_message("Configured!");
    // timer = timerBegin(0, 80, true);
    // timerAttachInterrupt(timer, &turn_off_display, true);
    // timerAlarmWrite(timer, 5000000, true);
    // timerAlarmEnable(timer);

    // loop();
    // esp_sleep_enable_timer_wakeup(TIME_TO_SLEEP * 60ULL * uS_TO_S_FACTOR);
    // esp_deep_sleep_start();
    xTaskCreatePinnedToCore(
      data_loop,   /* Task function */
      "Data Loop", /* Name for debugging */
      4096,           /* Stack depth in bytes */
      NULL,           /* Pass input parameters */
      1,              /* Task priority */
      NULL,           /* Task handle */
      1               /* Core ID (0 or 1) */
    );
};


void loop() {
    // if (!is_display_enabled) {
        // display->disable();
    // } else {
        if (xSemaphoreTake(global_lock, portMAX_DELAY) == pdTRUE) {
            if (current_packet != NULL) {

                float adc_voltage = adc_sensor->read_channel(0);
                Serial.print("ADC READ: ");
                Serial.println(adc_voltage);
                display->display_message(
                    "Time: " + rtc->get_time_formatted()
                    + "\nTemp: " + String(current_packet->bmp_temp) + " " + String(current_packet->dht_temp)
                    + "\nHum: " + String(current_packet->dht_hum)
                    + " P: " + String(current_packet->bmp_press)
                    + "\nV: " + String(current_packet->voltage)
                    + " A: " + String(current_packet->current)
                    + "\n Pw:" + String(current_packet->power) + "AD:" + String(adc_voltage)
                    + "\nAlt: " + String(current_packet->bmp_alt) + " m"
                    + " Dir: " + current_packet->wind_dir
                    + "\n Wind Speed: : " + current_packet->wind_speed
                );
                // timerAlarmWrite(timer, 5000000, true);
                // timerAlarmEnable(timer);
            }
            xSemaphoreGive(global_lock);
        }
    // }
    delay(500);
}

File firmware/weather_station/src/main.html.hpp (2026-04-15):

/*
 * =====================================================================================
 *
 *       Filename:  main.html.hpp
 *
 *    Description:  
 *
 *        Version:  1.0
 *        Created:  18/10/2025 03:29:53
 *       Revision:  none
 *       Compiler:  gcc
 *
 *         Author:  YOUR NAME (), 
 *   Organization:  
 *
 * =====================================================================================
 */
#ifndef MAIN_HTML_HPP
#define MAIN_HTML_HPP
#endif

const char index_html[] PROGMEM = R"====(
    <!DOCTYPE html>
    <html>
      <head>
        <link href="https://fonts.googleapis.com/css?family=Roboto:100,300,400,500,700,900|Material+Icons|Material+Icons+Outlined" rel="stylesheet" type="text/css">
        <link href="https://cdn.jsdelivr.net/npm/@mdi/font@^7.0.0/css/materialdesignicons.min.css" rel="stylesheet" type="text/css">
        <link href="https://cdn.jsdelivr.net/npm/quasar@2.18.2/dist/quasar.prod.css" rel="stylesheet" type="text/css">
      </head>

      <body>
        <div id="q-app">
            <q-layout view="hHh lpR fFf">
                <q-header bordered class="bg-primary text-white">
                  <q-toolbar>
                    <q-btn dense flat round icon="menu" @click="openSidebar = !openSidebar"></q-btn>

                    <q-toolbar-title>
                      <q-avatar>
                        <img src="https://app.metereolog.site/assets/logo-metereolog-white-D7FqNAoH.png">
                      </q-avatar>
                      Metereolog Station ARA 01
                    </q-toolbar-title>
                  </q-toolbar>
                </q-header>

                <q-drawer show-if-above v-model="openSidebar" side="left" bordered>
                    <q-list>
                        <template v-for="(menuItem, index) in menuList" :key="index">
                            <q-item clickable :href="menuItem.path">
                                <q-item-section avatar>
                                    <q-icon :name="menuItem.icon"></q-icon>
                                </q-item-section>
                                <q-item-section>
                                    {{ menuItem.label }}
                                </q-item-section>
                            </q-item>
                            <q-separator :key="'sep' + index"  v-if="menuItem.separator"></q-separator>
                        </template>
                    </q-list>
                </q-drawer>

                <q-page-container>
                    <q-page class="flex items-center justify-center">
                        <q-card style="max-width: 560px">
                            <q-card-section>
                                <div class="text-h4">Sensor Stats:</div>
                            </q-card-section
                            <q-separator inset></q-separator>
                            <q-card-section>
                                <q-list bordered separator>
                                    <q-item>
                                        <q-item-section avatar>
                                            <q-icon color="primary" name="mdi-thermometer" />
                                        </q-item-section>
                                        <q-item-section>
                                            <span style="text-size: 16px">
                                                Temperature (BMP): <b>{{ sensors.bmp.temperature }} &deg;C</b>
                                            </span>
                                        </q-item-section>
                                    </q-item>
                                    <q-item>
                                        <q-item-section avatar>
                                            <q-icon color="primary" name="mdi-altimeter" />
                                        </q-item-section>
                                        <q-item-section>
                                            <span style="text-size: 16px">
                                                Altitude (BMP): <b>{{ sensors.bmp.altitude }} m</b>
                                            </span>
                                        </q-item-section>
                                    </q-item>
                                    <q-item>
                                        <q-item-section avatar>
                                            <q-icon color="primary" name="mdi-gauge" />
                                        </q-item-section>
                                        <q-item-section>
                                            <span style="text-size: 16px">
                                                Pressure (BMP): <b>{{ sensors.bmp.pressure }} hPa</b>
                                            </span>
                                        </q-item-section>
                                    </q-item>
                                    <q-item>
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

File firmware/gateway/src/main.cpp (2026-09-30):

// RANSMISSOR OTIMIZADO - Heltec LoRa 32 V3
#include <Arduino.h>
#include <RadioLib.h>
#include <SPI.h>
#include <Wire.h>
#include <Adafruit_GFX.h>
#include <U8g2lib.h>
#include "lora.hpp"
#include "wifi.hpp"
#include "mqtt.hpp"
#include "oled.hpp"
#include "time.h"
#include "RTClib.h"
#include <ArduinoJson.h>

/* ============ WIFI CONFIGS ===================*/ 
const char* ssid = ENV_WIFI_SSID;
const char* password = ENV_WIFI_PASS;

MQTT *mqtt_client;
Wifi *wifi_client;

/* ============ BROKER CONFIGS ===================*/ 
const char *broker_user = ENV_BROKER_USER;
const char *broker_password = ENV_BROKER_PASS;
const char *broker_addr = ENV_BROKER_ADDR;
const int broker_port = atoi(ENV_BROKER_PORT);

const char *client_id = ENV_BROKER_CLIENT_ID;
const char *mqtt_topic = ENV_BROKER_TOPIC;

/* ================= LORA CONFIGS ===============*/
/* ================= For Heltec v3 ==============*/ 
// #define NSS_LORA   (gpio_num_t)   8
// #define DIO1_LORA  (gpio_num_t)   14
// #define RESET_LORA (gpio_num_t)   12
// #define BUSY_LORA  (gpio_num_t)   13
/* ================= For TTGO v2.1 ==============*/ 
#define NSS_LORA   (gpio_num_t)   18
#define DIO1_LORA  (gpio_num_t)   26
#define RESET_LORA (gpio_num_t)   14
#define BUSY_LORA  (gpio_num_t)   33
#define SCK     5
#define MISO    19
#define MOSI    27
#define DIO0    26
/* ==============================================*/
#define BAND          915.6
#define BANDWIDTH     62.5
#define SPREADING_FACTOR 10
#define CODING_RATE   4/5
#define LORA_POWER    22.0

/* ================= OLED CONFIGS ===============*/

// #define OLED_SDA (gpio_num_t) 17
// #define OLED_SCL (gpio_num_t) 18
// #define OLED_RST (gpio_num_t) 21
// #define VEXT_PIN (gpio_num_t) 36
// #define WIDTH  128
// #define HEIGHT 64
// 
// OLED *display;

/* ================= RTC CONFIGS ===============*/

// #define RTC_SDA (gpio_num_t) 46
// #define RTC_SCL (gpio_num_t) 45
// 
// TwoWire *rtc_i2c;
// RTC_DS1307 *rtc;

/* ============ CLOCK CONFIGS ===================*/ 
const char* ntpServer = "pool.ntp.org";
unsigned long epochTime; 

/* ============ SENSOR CONFIGS ===================*/ 
const char *dht_temp_id = ENV_DHT_TEMP_ID;
const char *dht_hum_id = ENV_DHT_HUM_ID;
const char *anemometer_id = ENV_ANEMOMETER_ID;
const char *anemoscope_id = ENV_ANEMOSCOPE_ID;
const char *pluviometer_id = ENV_PLUVIOMETER_ID;
const char *bmp_temp_id = ENV_BMP_TEMP_ID;
const char *bmp_alt_id = ENV_BMP_ALT_ID;
const char *bmp_press_id = ENV_BMP_PRESS_ID;
const char *voltmeter_id = ENV_VOLTMETER_ID;
const char *amperimeter_id = ENV_AMPERIMETER_ID;
// const char *power_id = ENV_POWER_ID;
const char *rssi_id = ENV_RSSI_ID;
const char *snr_id = ENV_SNR_ID;

JsonDocument doc;
char msg_buffer[1280]; 

/* ==============================================*/

long packet_id = 0;
// U8G2_SSD1306_128X64_NONAME_F_SW_I2C display(U8G2_R0, OLED_SCL, OLED_SDA, OLED_RESET);
LoRa *lora = new LoRa(NSS_LORA, DIO1_LORA, RESET_LORA, BUSY_LORA, BAND, BANDWIDTH, SPREADING_FACTOR, CODING_RATE, LORA_POWER, Receptor);



typedef struct __attribute__((packed)) {
    char device_id[33];
    unsigned long timestamp;
    char wind_dir[3];
    float dht_hum;
    float dht_temp;
    float wind_speed;
    float rain_gauge;
    float bmp_temp;
    float bmp_alt;
    float bmp_press;
    float voltage;
    float current;
    // float power;
} Packet;

void deserialize_packet(String raw_packet, Packet* p) {
    sscanf(
        raw_packet.c_str(),
        "%32s|%lu|%2[^|]|%f|%f|%f|%f|%f|%f|%f|%f|%f|%f",
        p->device_id,
        &p->timestamp,
        p->wind_dir,
        &p->dht_hum,
        &p->dht_temp,
        &p->wind_speed,
        &p->rain_gauge,
        &p->bmp_temp,
        &p->bmp_alt,
        &p->bmp_press,
        &p->voltage,
        &p->current
       //  &p->power
    );
}


void pretty_print_packet(const Packet* p, String snr, String rssi) {
  Serial.println("Packet {");
  Serial.print("    device_id = ");   Serial.print(p->device_id);  Serial.println(",");
  Serial.print("    timestamp = ");   Serial.print(p->timestamp);  Serial.println(",");
  Serial.print("    wind_dir = ");    Serial.print(p->wind_dir);   Serial.println(",");
  Serial.print("    dht_hum = ");     Serial.print(p->dht_hum);    Serial.println(",");
  Serial.print("    dht_temp = ");    Serial.print(p->dht_temp);   Serial.println(",");
  Serial.print("    wind_speed = ");  Serial.print(p->wind_speed); Serial.println(",");
  Serial.print("    rain_gauge = ");  Serial.print(p->rain_gauge); Serial.println(",");
  Serial.print("    bmp_temp = ");    Serial.print(p->bmp_temp);   Serial.println(",");
  Serial.print("    bmp_alt = ");     Serial.print(p->bmp_alt);    Serial.println(",");
  Serial.print("    bmp_press = ");   Serial.print(p->bmp_press);  Serial.println(",");
  Serial.print("    voltage = ");     Serial.print(p->voltage);    Serial.println(",");
  Serial.print("    current = ");     Serial.print(p->current);    Serial.println(",");
  // Serial.print("    power = ");     Serial.print(p->power);    Serial.println(",");
  Serial.print("    snr = ");    Serial.print(snr);   Serial.println(",");
  Serial.print("    rssi = ");    Serial.print(rssi);   Serial.println(",");
  Serial.println("}");
}

// void setup_display() {
//     display = new OLED(OLED_SDA, OLED_SCL, OLED_RST, VEXT_PIN, WIDTH, HEIGHT);
//     display->begin();
// }

// unsigned long getTime() {
//   time_t now;
//   struct tm timeinfo;
//   while(!getLocalTime(&timeinfo)) {
//     Serial.println("Failed to obtain time");
//   }
//   time(&now);
//   return now;
// }

// void setup_rtc() {
//     Serial.println("Starting configuration of RTC...");
//     rtc_i2c = new TwoWire(1);
//     rtc_i2c->begin(RTC_SDA, RTC_SCL);
//     rtc = new RTC_DS1307();
//     while (!rtc->begin(rtc_i2c)) {
//         Serial.println("Error while configuring RTC module");
//         delay(500);
//         break;
//     }
//     unsigned long timestamp = getTime();
//     if (!rtc->isrunning()) {
//         Serial.println("Configuring RTC...");
//         rtc->adjust(timestamp);
//     }
//     DateTime time = rtc->now();
//     // delay(5000);
// }
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

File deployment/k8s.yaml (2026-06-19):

apiVersion: apps/v1
kind: Deployment
metadata:
  name: metereolog-stack
  namespace: metereolog
  labels:
    app: metereolog-stack
spec:
  replicas: 1
  selector:
    matchLabels:
      app: metereolog-stack
  template:
    metadata:
      labels:
        app: metereolog-stack
    spec:
      initContainers:
        - name: migration-applier
          image: claudinoac/metereolog-server:v1
          imagePullPolicy: Always
          command: ["python", "manage.py", "migrate", "--noinput"]
          env:
          - name: SECRET_KEY
            valueFrom:
              secretKeyRef:
                name: metereolog-api-creds
                key: secret_key
          - name: RABBITMQ_ADDR 
            valueFrom:
              secretKeyRef:
                name: metereolog-api-creds
                key: rabbitmq_host
          - name: RABBITMQ_DEFAULT_USER
            valueFrom:
              secretKeyRef:
                name: metereolog-api-creds
                key: rabbitmq_user
          - name: RABBITMQ_DEFAULT_PASS
            valueFrom:
              secretKeyRef:
                name: metereolog-api-creds
                key: rabbitmq_pwd
          - name: POSTGRES_USER
            valueFrom:
              secretKeyRef:
                name: metereolog-api-creds
                key: postgres_user
          - name: POSTGRES_PASSWORD
            valueFrom:
              secretKeyRef:
                name: metereolog-api-creds
                key: postgres_pwd
          - name: DJANGO_SETTINGS_MODULE
            value: "metereolog.settings.production"
          - name: POSTGRES_DB
            valueFrom:
              secretKeyRef:
                name: metereolog-api-creds
                key: postgres_db
          - name: POSTGRES_HOST
            valueFrom:
              secretKeyRef:
                name: metereolog-api-creds
                key: postgres_host
      containers:
      - name: api
        image: claudinoac/metereolog-server:v1
        imagePullPolicy: Always
        command: ["gunicorn", "-c", "gunicorn.conf.py", "metereolog.wsgi:application"]
        ports:
        - containerPort: 8009
        env:
          - name: SECRET_KEY
            valueFrom:
              secretKeyRef:
                name: metereolog-api-creds
                key: secret_key
          - name: RABBITMQ_ADDR 
            valueFrom:
              secretKeyRef:
                name: metereolog-api-creds
                key: rabbitmq_host
          - name: RABBITMQ_DEFAULT_USER
            valueFrom:
              secretKeyRef:
                name: metereolog-api-creds
                key: rabbitmq_user
          - name: RABBITMQ_DEFAULT_PASS
            valueFrom:
              secretKeyRef:
                name: metereolog-api-creds
                key: rabbitmq_pwd
          - name: POSTGRES_USER
            valueFrom:
              secretKeyRef:
                name: metereolog-api-creds
                key: postgres_user
          - name: POSTGRES_PASSWORD
            valueFrom:
              secretKeyRef:
                name: metereolog-api-creds
                key: postgres_pwd
          - name: DJANGO_SETTINGS_MODULE
            value: "metereolog.settings.production"
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

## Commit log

2025-04-25 Implementação de dois sensores (#7)
    * Implementação de dois sensores
    * mudando idioma para ingles
    * Criando README para os sensores
    * fix: remove specific vscode extension files
    * fix: docs & code readability
    * fix: calibration of wind direction sensor
    * fix: integrate with existing code
    ---------
    [main.cpp]
2025-04-26 Sensors/mq6 anemometer (#12)
    * Implementa sensor MQ‑6 e anemômetro
    - Adiciona drivers em lib/
    - Ajusta main.cpp
    * Documentação basica
    * Documentação DHT11 e Anemometer
    Altereções no codigo do Anemometer e main
    * Alteraçao documentaçao DHT11
    * Alteração na logicado Anemometer
    * fix: integrate all sensors
    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
    [main.cpp]
2025-05-13 [ML-17] Implement Sensor Model (#30)
    * [ML-15] Implement Role Model
    * [ML-17] Implement Sensor Model
    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
2025-05-13 [ML-17] Implement Sensor Model
2025-05-13 [ML-21] feat: Implement Sensor Reading entity and Configure TimescaleDB
2025-05-13 fix: mqtt buffer + final payload format
    [main.cpp]
2025-05-29 [ML-20] feat: implement UI pages and endpoints
    - [ML-34] feat: Login UI page
    - [ML-28] feat: Login API endpoint
    - [ML-31] feat: Devices List UI page
    - [ML-32] feat: Sensor List & Device Dashboard UI Page
    - [ML-25] feat: Device API endpoints: List, Get
    - [ML-26] feat: Sensor API endpoints: List
    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
2025-05-30 docs: allow falsy sensor reading values to be stored
2025-06-29 refactor: allow free date selection for sensor dashboard
2025-07-02 [ML-31] feat: implement device creation page
2025-07-02 [ML-32] feat: implement sensor create and delete operations
2025-07-02 fix: time ranges on charts
    [serializers.py, views.py]
2025-07-03 [ML-31] refactor: show all device details in dashboard
2025-07-03 [ML-31] refactor: add predefined time filters
2025-07-03 [ML-31] refactor: add more space between device details
2025-07-04 [ML-32] feat: add more ticks on y axis
2026-04-20 docs: update description with LoRa devices
2026-06-19 feat: circuit diagrams and kicad libs
    [metereolog-B_Adhesive.gbr, metereolog-B_Cu.gbr, metereolog-B_Fab.gbr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]
2026-09-30 refactor: new gateway and redesigned weather station
    [main.cpp]
2026-10-07 Update pluviometer code
    This commit hardens the rain sensor interrupt path by adding an ISR mutex. It also resets the counter after each read, exposes rain data in mm and mL using configurable resolution/diameter settings, and updates the main sensor packet to publish the corrected rain-gauge value. A PlatformIO .gitignore was also added for the weather station firmware project.
    [main.cpp]
